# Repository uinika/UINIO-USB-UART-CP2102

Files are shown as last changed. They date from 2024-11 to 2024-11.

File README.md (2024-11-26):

# UINIO-USB-UART-CP2102 串口调试器

[**UINIO-USB-UART-CP2102**](https://gitee.com/uinika/UINIO-USB-UART-CP2102) 是一款基于 [**美国芯科 CP2102**](https://www.silabs.com/interface/usb-bridges/classic/device.cp2102) 芯片的 **USB** 转 **UART** 的开源串口调试器，该款芯片采用 `QFN28` 封装，可以稳定支持 `921600` 波特率的 UART 串口通信。

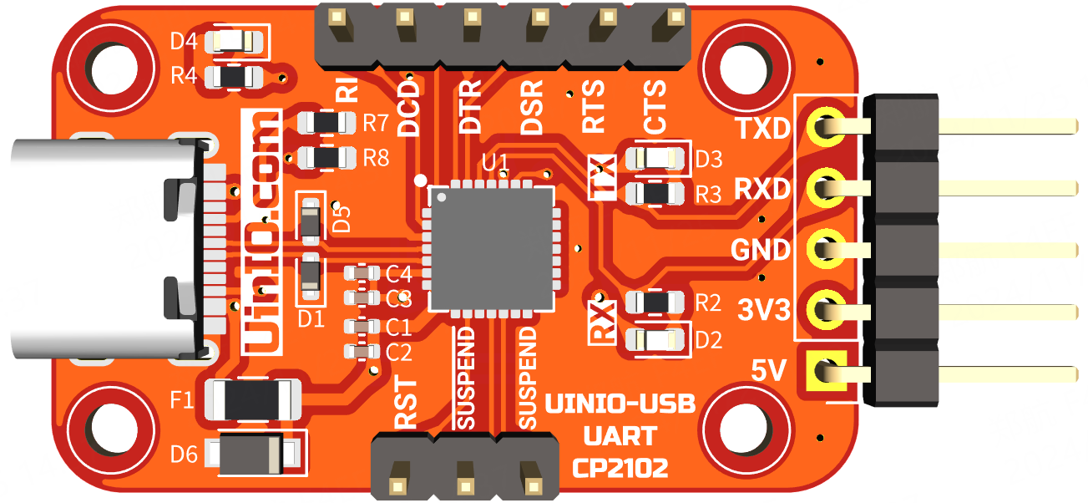
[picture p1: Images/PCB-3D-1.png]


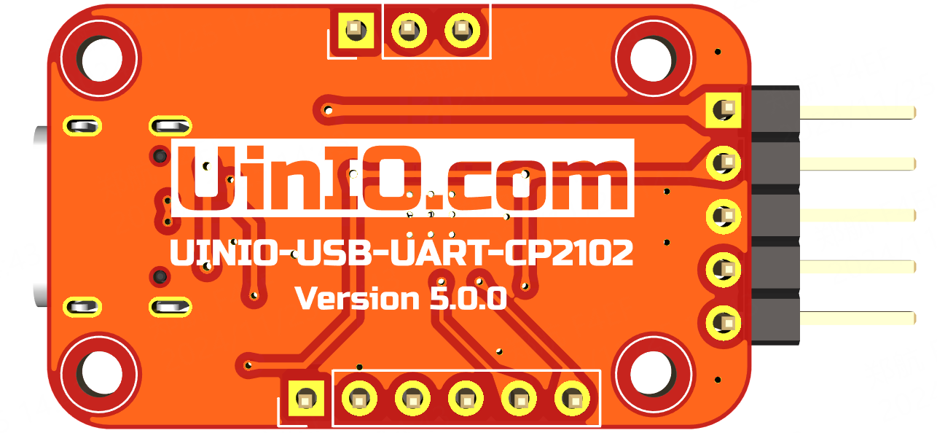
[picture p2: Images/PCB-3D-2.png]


## 设计概要

1. 板载 `RXD` 和 `TXD` 的信号传输状态指示灯；
2. USB 信号线上并入了两枚 TVS 瞬态电压抑制二极管；
3. 引出了包括**串口硬件流控信号线**在内的全部片上资源；
4. 为 `5V` 输出提供了**自恢复保险丝**和**二极管**组成的防反接保护电路；
5. 预留有 `2mm` 的固定螺丝孔，便于安装至 3D 打印外壳，或者搭建成套的产品原型；

## 参考技术文档

[UinIO.com 电子技术实验室](http://uinio.com/) 为 **UINIO-USB-UART-CP2102** 开源项目提供了如下一系列技术参考资料：

- [《UINIO-DAPLink 核心板原理图》](http://uinio.com/my/works/UINIO-USB-UART-CP2102/UINIO-USB-UART-CP2102-Schematic.pdf)
- [《交互式 BOM 物料清单与 PCB 版图在线预览》](http://uinio.com/my/works/UINIO-USB-UART-CP2102/UINIO-USB-UART-CP2102-BOM.html)

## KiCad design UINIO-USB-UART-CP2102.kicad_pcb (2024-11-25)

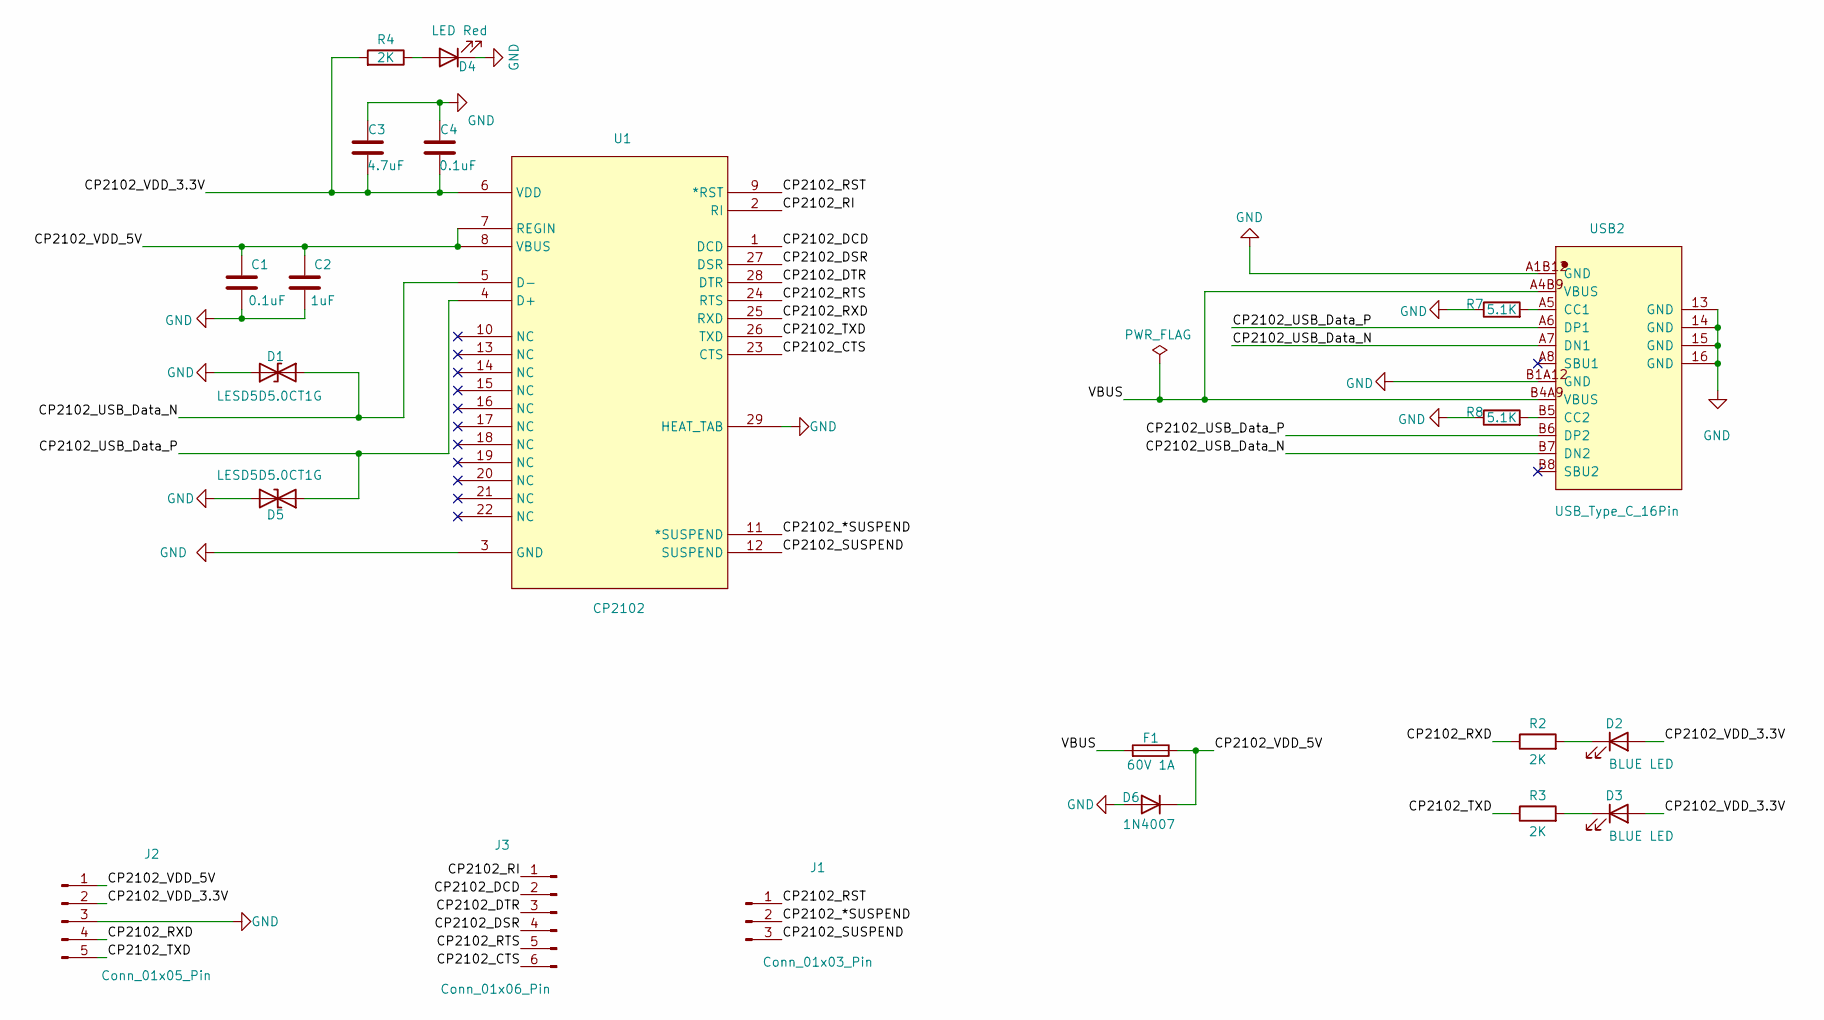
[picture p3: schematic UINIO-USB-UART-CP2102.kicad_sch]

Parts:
C1, C4: 0.1uF; C_0402_1005Metric
C2: 1uF; C_0402_1005Metric
C3: 4.7uF; C_0402_1005Metric
D1, D5: LESD5D5.0CT1G; D_SOD-523
D2, D3: BLUE LED; LED_0603_1608Metric
D4: LED Red; LED_0603_1608Metric
D6: 1N4007; Nexperia_CFP3_SOD-123W
F1: 60V 1A; Fuse_1206_3216Metric
J1: Conn_01x03_Pin; PinHeader_1x03_P2.54mm_Vertical
J2: Conn_01x05_Pin; PinHeader_1x05_P2.54mm_Vertical
J3: Conn_01x06_Pin; PinHeader_1x06_P2.54mm_Vertical
R2, R3, R4: 2K; R_0603_1608Metric
R7, R8: 5.1K; R_0603_1608Metric
U1: CP2102; QFN-28_L5.0-W5.0-P0.50-TL-EP3.3; MFG #1 SILICON LABS
USB2: USB_Type_C_16Pin; USB-C-SMD_TYPEC-304J-BCP16

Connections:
/CP2102_*SUSPEND: J1.2, U1.11 (*SUSPEND)
/CP2102_CTS: J3.6, U1.23 (CTS)
/CP2102_DCD: J3.2, U1.1 (DCD)
/CP2102_DSR: J3.4, U1.27 (DSR)
/CP2102_DTR: J3.3, U1.28 (DTR)
/CP2102_RI: J3.1, U1.2 (RI)
/CP2102_RST: J1.1, U1.9 (*RST)
/CP2102_RTS: J3.5, U1.24 (RTS)
/CP2102_RXD: J2.4, R2.1, U1.25 (RXD)
/CP2102_SUSPEND: J1.3, U1.12 (SUSPEND)
/CP2102_TXD: J2.5, R3.1, U1.26 (TXD)
/CP2102_USB_Data_N: D1.2 (A2), U1.5 (D-), USB2.A7 (DN1), USB2.B7 (DN2)
/CP2102_USB_Data_P: D5.2 (A2), U1.4 (D+), USB2.A6 (DP1), USB2.B6 (DP2)
/CP2102_VDD_3.3V: C3.1, C4.1, D2.2 (A), D3.2 (A), J2.2, R4.2, U1.6 (VDD)
/CP2102_VDD_5V: C1.1, C2.1, D6.1 (K), F1.1, J2.1, U1.7 (REGIN), U1.8 (VBUS)
/VBUS: F1.2, USB2.A4B9 (VBUS), USB2.B4A9 (VBUS)
GND: C1.2, C2.2, C3.2, C4.2, D1.1 (A1), D4.1 (K), D5.1 (A1), D6.2 (A), J2.3, R7.1, R8.1, U1.3 (GND), U1.29 (HEAT_TAB), USB2.13 (GND), USB2.14 (GND), USB2.15 (GND), USB2.16 (GND), USB2.A1B12 (GND), USB2.B1A12 (GND)
unnamed: D2.1 (K), R2.2
unnamed: D3.1 (K), R3.2
unnamed: D4.2 (A), R4.1
unnamed: R7.2, USB2.A5 (CC1)
unnamed: R8.2, USB2.B5 (CC2)

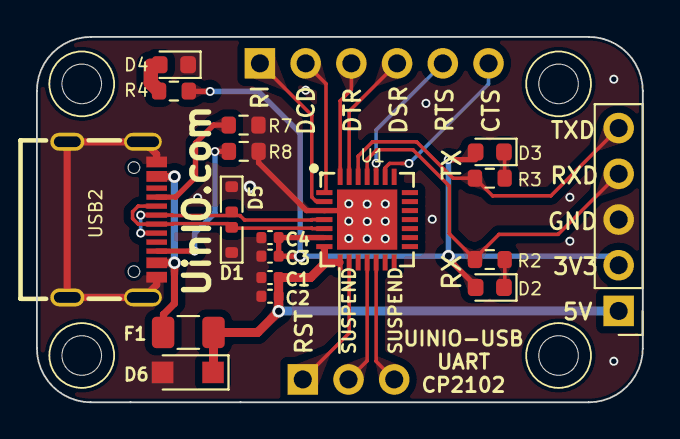
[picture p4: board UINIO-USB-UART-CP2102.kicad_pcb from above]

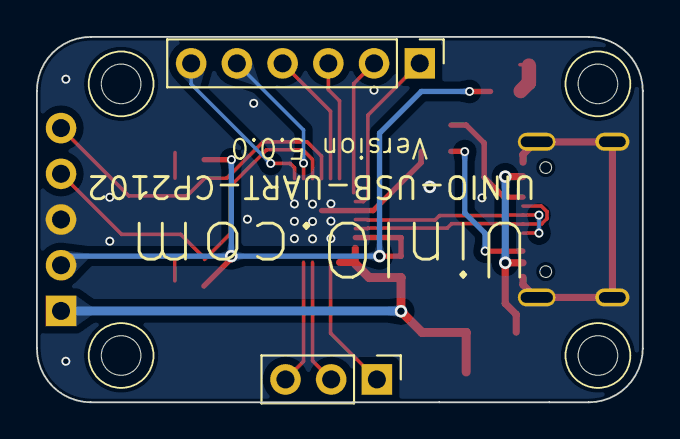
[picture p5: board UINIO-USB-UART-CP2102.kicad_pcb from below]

Board: 2 copper layers, 33.7 x 20.3 mm, 25 parts (2 on the bottom side), 22 nets.

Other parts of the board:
HOLE**: Hole-2mm
HOLE**#2, HOLE**#3, HOLE**#4: Hole-2mm
